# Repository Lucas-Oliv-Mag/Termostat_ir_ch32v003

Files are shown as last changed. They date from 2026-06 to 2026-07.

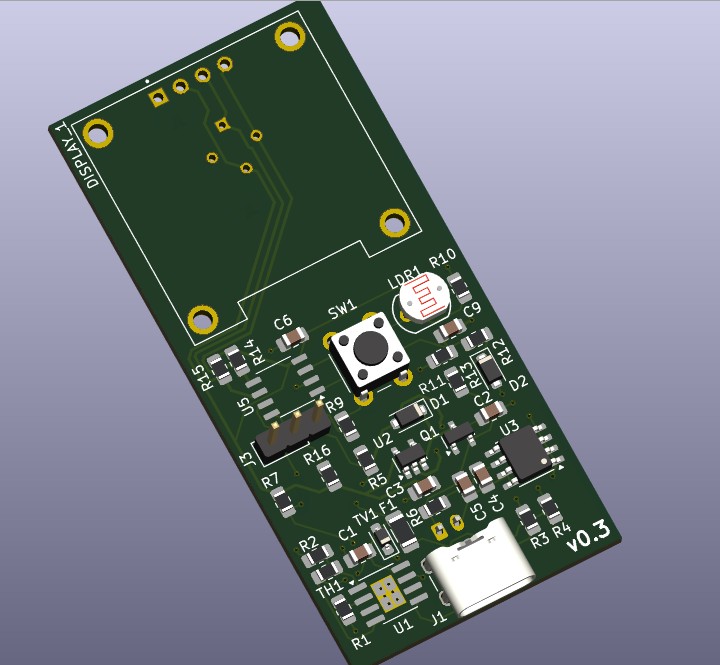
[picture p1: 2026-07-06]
docs/realises/v0.3/IR_Termostat_v0.3.jpg

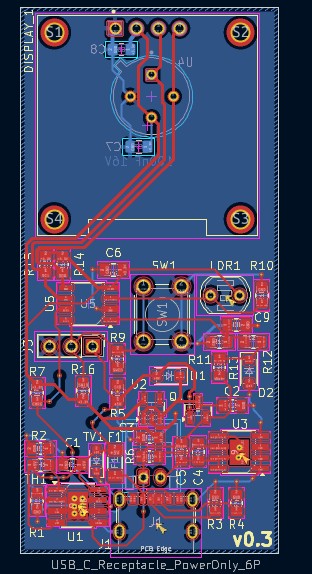
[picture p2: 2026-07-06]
docs/realises/v0.3/pcb_img.jpg

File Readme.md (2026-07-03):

# 🌡️ IR Thermostat — CH32V003

A portable, compact, low-power infrared thermometer based on the **CH32V003** microcontroller, featuring contactless temperature reading via the **MLX90614** sensor and an **I²C OLED SSD1306** display.

Built with **100% custom firmware** — HAL and sensor libraries written from scratch, with no dependency on third-party frameworks.

---

## ✨ Features

- 📡 Contactless infrared temperature reading via **MLX90614**
- 🖥️ **128x64 SSD1306 OLED** display over I²C
- 🔘 Single tactile button to trigger a reading
- 🌗 **Automatic brightness control** via a 5mm LDR (adjusts to ambient light)
- 🔋 **250mAh LiPo battery (503020)** for portable use
- ⚡ Charging via **TP4056** with integrated battery protection (0.5C)
- 🔌 3-pin header (5V / GND / SWIO) for external power and programming

---

## 🧩 Hardware

| Component | Description |
|---|---|
| **MCU** | CH32V003 (RISC-V, low cost, low power) |
| **Temperature sensor** | MLX90614 (IR, I²C) |
| **Display** | SSD1306 OLED 128x64, I²C |
| **Light sensor** | 5mm LDR (automatic brightness control) |
| **Input** | 1x tactile button (start/reading) |
| **Power source** | 250mAh LiPo battery, 503020 |
| **Charger** | TP4056 with battery protection (over-charge/discharge/current) |
| **Charge rate** | 0.5C (~125mA) |
| **External connector** | 3-pin header — 5V, GND, SWIO |

---

## ⚠️ Important warnings

> **Read carefully before using or programming the device.**

### 🚫 Never flash the MCU while pressing the button
The **SWIO** pin (used for programming/debugging) shares the same **I/O line** as the tactile button. Pressing the button during flashing can cause a **bus conflict**, flashing failure, or undefined MCU behavior.

### 🚫 Never connect USB while powering via the external 5V header
The **TP4056** charger and the 3-pin header **have no isolation between power sources**. Powering the circuit simultaneously through **USB** and the **external header (5V)** can cause:
- Short circuit between power sources
- Unwanted reverse current
- Damage to the TP4056, the battery, or the MCU

**Use only one power source at a time.**

---

## 🌡️ Operating conditions

- **Maximum recommended ambient temperature:** ~40 °C
- Above this limit, the MLX90614 sensor accuracy and the LiPo battery lifespan may be affected.

---

## 🔋 Battery and charging

| Parameter | Value |
|---|---|
| Capacity | 250 mAh |
| Model | 503020 (LiPo) |
| Charge rate | 0.5C (~125 mA) |
| Charge controller | TP4056 |
| Protection | Over-charge, over-discharge, and over-current |

---

## 💻 Firmware

The firmware is **built entirely from scratch**, without relying on any third-party HAL (such as the official WCH HAL), including:

- **Custom HAL** for GPIO, I²C, ADC, and timing on the CH32V003
- **Custom library** for MLX90614 communication
- **Custom library** for SSD1306 display control
- LDR reading routine with a brightness adjustment curve (PWM/lookup table)
- Simple state machine: `standby → reading → display → standby`

### repository structure

```
/firmware
  /*COMING SOON*
/hardware
  /schematics
  /pcb
  /datasheets
/docs
README.md
LICENSE
```

---

## 🚀 Usage

1. Power the device via battery (or the external 5V header, **never both at the same time**).
2. Press the tactile button to start a temperature reading.
3. The temperature will be shown on the OLED display.
4. The display brightness adjusts automatically based on the ambient light detected by the LDR.

---

## 🛠️ Flashing

1. Connect the programmer (WCH-Link or compatible) to the 3-pin header (**5V / GND / SWIO**).
2. **Make sure the tactile button is not being pressed.**
3. Flash normally using your preferred tool (e.g., `wchisp`, MounRiver, OpenOCD with RISC-V support).

---

## 🤝 Contributing

Suggestions, fixes, and improvements are welcome via issues or pull requests.

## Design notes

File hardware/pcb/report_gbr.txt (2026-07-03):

Plotted to 'H:\Meu Drive\WorkStation\Embarcados\Projetos\IR Termostat\hardware\pcb\IR_Termostat-F_Cu.gbr'.
Plotted to 'H:\Meu Drive\WorkStation\Embarcados\Projetos\IR Termostat\hardware\pcb\IR_Termostat-B_Cu.gbr'.
Plotted to 'H:\Meu Drive\WorkStation\Embarcados\Projetos\IR Termostat\hardware\pcb\IR_Termostat-F_Paste.gbr'.
Plotted to 'H:\Meu Drive\WorkStation\Embarcados\Projetos\IR Termostat\hardware\pcb\IR_Termostat-B_Paste.gbr'.
Plotted to 'H:\Meu Drive\WorkStation\Embarcados\Projetos\IR Termostat\hardware\pcb\IR_Termostat-F_Silkscreen.gbr'.
Plotted to 'H:\Meu Drive\WorkStation\Embarcados\Projetos\IR Termostat\hardware\pcb\IR_Termostat-B_Silkscreen.gbr'.
Plotted to 'H:\Meu Drive\WorkStation\Embarcados\Projetos\IR Termostat\hardware\pcb\IR_Termostat-F_Mask.gbr'.
Plotted to 'H:\Meu Drive\WorkStation\Embarcados\Projetos\IR Termostat\hardware\pcb\IR_Termostat-B_Mask.gbr'.
Plotted to 'H:\Meu Drive\WorkStation\Embarcados\Projetos\IR Termostat\hardware\pcb\IR_Termostat-Edge_Cuts.gbr'.
Created Gerber job file 'H:\Meu Drive\WorkStation\Embarcados\Projetos\IR Termostat\hardware\pcb\IR_Termostat-job.gbrjob'.
Informação: Done.
Informação: Done.

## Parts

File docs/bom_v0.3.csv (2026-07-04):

Reference | Qty | Value | DNP | Exclude from BOM | Exclude from Board | Footprint | Datasheet
BT1 | 1 | 250mAh |  | Excluído do BOM | Excluída da placa |  | ~
C1,C5 | 2 | 10uF 16V |  |  |  | Capacitor_SMD:C_0805_2012Metric_Pad1.18x1.45mm_HandSolder | ~
C2,C3 | 2 | 1uF 16V |  |  |  | Capacitor_SMD:C_0805_2012Metric_Pad1.18x1.45mm_HandSolder | ~
C4,C6,C7,C8,C9 | 5 | 100nF 16V |  |  |  | Capacitor_SMD:C_0805_2012Metric_Pad1.18x1.45mm_HandSolder | ~
D1 | 1 | PMEG2005EH |  |  |  | Diode_SMD:D_SOD-123F | https://assets.nexperia.com/documents/data-sheet/PMEGXX05EH_EJ_SER.pdf
D2 | 1 | BZT52C4V7 |  |  |  | Diode_SMD:D_SOD-123F | https://www.lcsc.com/datasheet/C2903911.pdf
DISPLAY_1 | 1 | DM-OLED096-636 |  |  |  | Library:MODULE_DM-OLED096-636
F1 | 1 | 250mA PPTC |  |  |  | Resistor_SMD:R_1206_3216Metric_Pad1.30x1.75mm_HandSolder | https://www.lcsc.com/datasheet/C70070.pdf
J1 | 1 | USB_C_Receptacle_PowerOnly_6P |  |  |  | Connector_USB:USB_C_Receptacle_GCT_USB4125-xx-x_6P_TopMnt_Horizontal | https://www.usb.org/sites/default/files/documents/usb_type-c.zip
J2 | 1 | JST-PH-2mm |  |  |  | Connector_JST:JST_PH_S2B-PH-K_1x02_P2.00mm_Horizontal | ~
J3 | 1 | Conn_01x03_Pin |  |  |  | Connector_PinHeader_2.54mm:PinHeader_1x03_P2.54mm_Vertical | ~
LDR1 | 1 | GL5516 |  |  |  | OptoDevice:R_LDR_5.1x4.3mm_P3.4mm_Vertical | http://www.tme.eu/de/Document/f2e3ad76a925811312d226c31da4cd7e/LDR07.pdf
Q1 | 1 | FDN306P |  |  |  | Package_TO_SOT_SMD:SOT-23 | https://www.lcsc.com/datasheet/C154510.pdf
R1,R7,R10 | 3 | 10K 1% |  |  |  | Resistor_SMD:R_0805_2012Metric_Pad1.20x1.40mm_HandSolder | ~
R2,R5,R16 | 3 | 22K 1% |  |  |  | Resistor_SMD:R_0805_2012Metric_Pad1.20x1.40mm_HandSolder | ~
R3,R4,R14,R15 | 4 | 5.1K 1% |  |  |  | Resistor_SMD:R_0805_2012Metric_Pad1.20x1.40mm_HandSolder | ~
R6,R9,R13 | 3 | 1K 1% |  |  |  | Resistor_SMD:R_0805_2012Metric_Pad1.20x1.40mm_HandSolder | ~
R11 | 1 | 2M 1% |  |  |  | Resistor_SMD:R_0805_2012Metric_Pad1.20x1.40mm_HandSolder | ~
R12 | 1 | 1M 1% |  |  |  | Resistor_SMD:R_0805_2012Metric_Pad1.20x1.40mm_HandSolder | ~
SW1 | 1 | SW_SPST |  |  |  | Button_Switch_THT:SW_PUSH_6mm | ~
TH1 | 1 | 10KF3950 NTC |  |  |  | Resistor_SMD:R_0805_2012Metric_Pad1.20x1.40mm_HandSolder | https://www.lcsc.com/datasheet/C2892549.pdf
TV1 | 1 | PESD5V0S1BA |  |  |  | Diode_SMD:D_SOD-323_HandSoldering | https://www.lcsc.com/datasheet/C2827694.pdf
U1 | 1 | TP4056-42-ESOP8 |  |  |  | Package_SO:SOIC-8-1EP_3.9x4.9mm_P1.27mm_EP2.41x3.3mm_ThermalVias | https://www.lcsc.com/datasheet/lcsc_datasheet_2410121619_TOPPOWER-Nanjing-Extension-Microelectronics-TP4056-42-ESOP8_C16581.pdf
U2 | 1 | TPS7A0233DBVR |  |  |  | Package_TO_SOT_SMD:SOT-23-5 | https://www.ti.com/lit/ds/symlink/tps7a02.pdf?ts=1783134422574
U3 | 1 | XB8089D |  |  |  | Package_SO:SOIC-8-1EP_3.9x4.9mm_P1.27mm_EP2.29x3mm_ThermalVias | https://www.lcsc.com/datasheet/C79928.pdf
U4 | 1 | MLX90614ESF-BAA-000-TU |  |  |  | Library:TO254P942H425-4 | https://www.lcsc.com/datasheet/C490604.pdf
U5 | 1 | CH32V003JxMx |  |  |  | Package_SO:SOP-8_3.9x4.9mm_P1.27mm | https://www.wch-ic.com/products/CH32V003.html

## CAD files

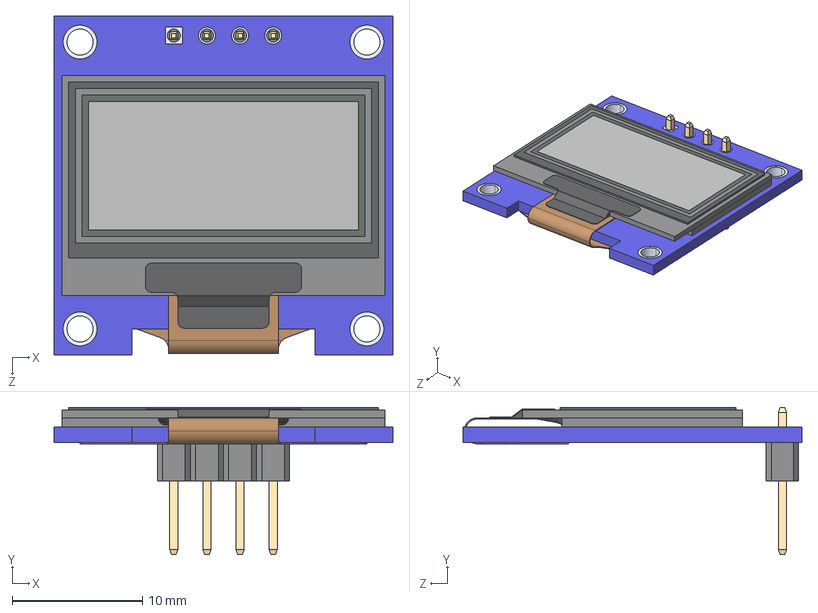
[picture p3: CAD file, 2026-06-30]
hardware/schematics/symbols_footprints/DM-OLED096-636/DM-OLED096-636.step
26.0 x 11.3 x 26.0 mm
DM-OLED096-636_Module
DM-OLED096-636_Panel

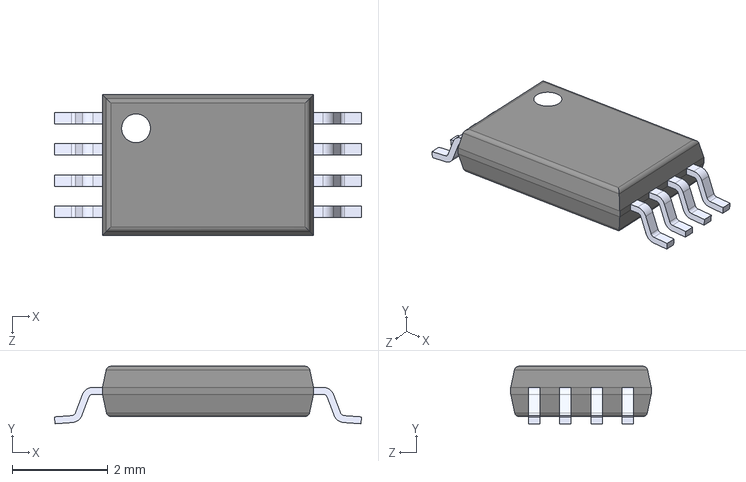
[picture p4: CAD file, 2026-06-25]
hardware/schematics/symbols_footprints/FS8205A/FS8205A.step
6.40 x 1.20 x 2.93 mm

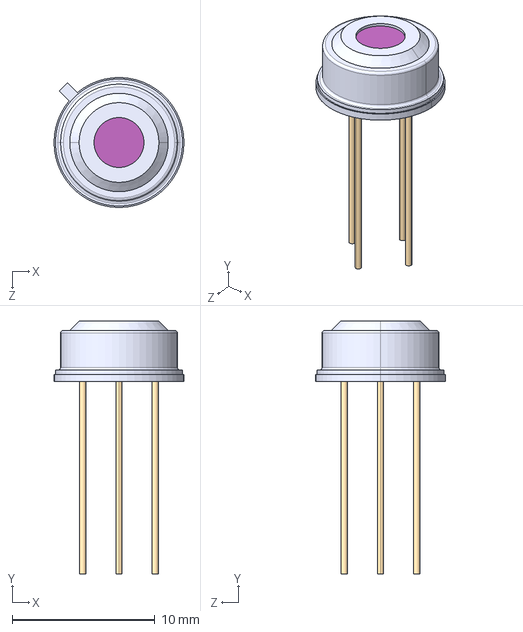
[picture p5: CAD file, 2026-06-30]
hardware/schematics/symbols_footprints/MLX90614ESF-BAA-000-TU/MLX90614ESF-BAA-000-TU.step
9.12 x 17.8 x 9.12 mm

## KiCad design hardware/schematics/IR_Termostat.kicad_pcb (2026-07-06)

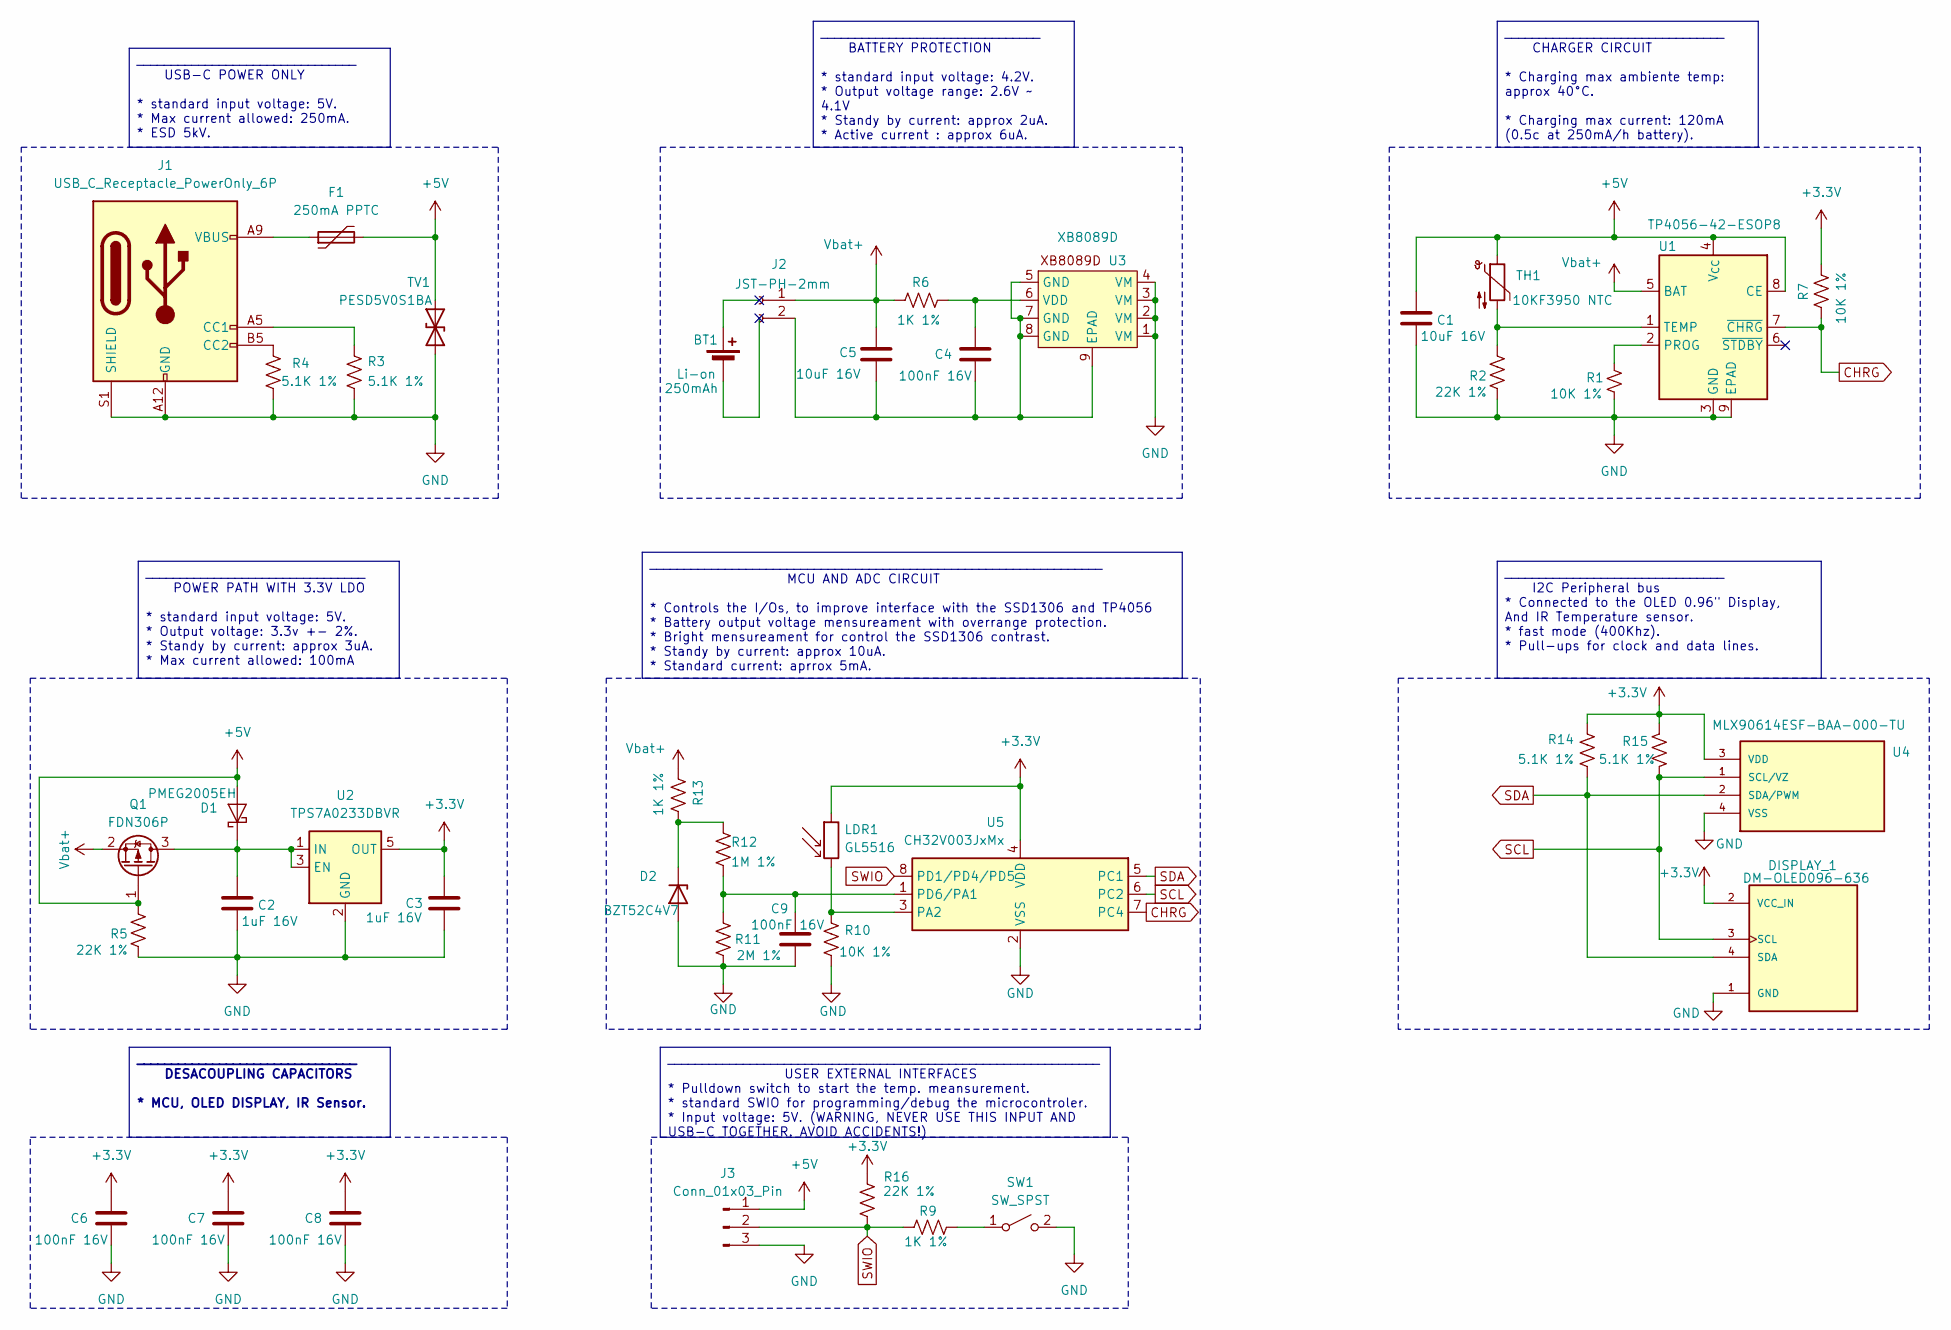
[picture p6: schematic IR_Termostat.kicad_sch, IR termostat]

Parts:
BT1: 250mAh
C1, C5: 10uF 16V; C_0805_2012Metric_Pad1.18x1.45mm_HandSolder
C2, C3: 1uF 16V; C_0805_2012Metric_Pad1.18x1.45mm_HandSolder
C4, C6, C7, C8, C9: 100nF 16V; C_0805_2012Metric_Pad1.18x1.45mm_HandSolder
D1: PMEG2005EH; D_SOD-123F
D2: BZT52C4V7; D_SOD-123F
DISPLAY_1: DM-OLED096-636; MODULE_DM-OLED096-636; PARTREV 2018-09-10
F1: 250mA PPTC; R_1206_3216Metric_Pad1.30x1.75mm_HandSolder
J1: USB_C_Receptacle_PowerOnly_6P; USB_C_Receptacle_GCT_USB4125-xx-x_6P_TopMnt_Horizontal
J2: JST-PH-2mm; JST_PH_S2B-PH-K_1x02_P2.00mm_Horizontal
J3: Conn_01x03_Pin; PinHeader_1x03_P2.54mm_Vertical
LDR1: GL5516; R_LDR_5.1x4.3mm_P3.4mm_Vertical
Q1: FDN306P; SOT-23
R1, R7, R10: 10K 1%; R_0805_2012Metric_Pad1.20x1.40mm_HandSolder
R2, R5, R16: 22K 1%; R_0805_2012Metric_Pad1.20x1.40mm_HandSolder
R3, R4, R14, R15: 5.1K 1%; R_0805_2012Metric_Pad1.20x1.40mm_HandSolder
R6, R9, R13: 1K 1%; R_0805_2012Metric_Pad1.20x1.40mm_HandSolder
R11: 2M 1%; R_0805_2012Metric_Pad1.20x1.40mm_HandSolder
R12: 1M 1%; R_0805_2012Metric_Pad1.20x1.40mm_HandSolder
SW1: SW_SPST; SW_PUSH_6mm
TH1: 10KF3950 NTC; R_0805_2012Metric_Pad1.20x1.40mm_HandSolder
TV1: PESD5V0S1BA; D_SOD-323_HandSoldering
U1: TP4056-42-ESOP8; SOIC-8-1EP_3.9x4.9mm_P1.27mm_EP2.41x3.3mm_ThermalVias
U2: TPS7A0233DBVR; SOT-23-5
U3: XB8089D; SOIC-8-1EP_3.9x4.9mm_P1.27mm_EP2.29x3mm_ThermalVias
U4: MLX90614ESF-BAA-000-TU; TO254P942H425-4; PARTREV 13
U5: CH32V003JxMx; SOP-8_3.9x4.9mm_P1.27mm

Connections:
+3.3V: C3.1, C6.1, C7.1, C8.1, DISPLAY_1.2 (VCC_IN), LDR1.1, R7.2, R14.2, R15.2, R16.2, U2.5 (OUT), U4.3 (VDD), U5.4 (VDD)
+5V: C1.1, D1.2 (A), F1.2, J3.1, Q1.1 (G), R5.1, TH1.1, TV1.2 (A2), U1.4 (V_{CC}), U1.8 (CE)
CHRG: R7.1, U1.7 (~CHRG), U5.7 (PC4)
GND: C1.2, C2.2, C3.2, C6.2, C7.2, C8.2, C9.2, D2.2 (A), DISPLAY_1.1 (GND), J1.A12 (GND), J1.B12 (GND), J1.S1 (SHIELD), J3.3, R1.2, R2.2, R3.2, R4.2, R5.2, R10.2, R11.2, SW1.2 (B), TV1.1 (A1), U1.3 (GND), U1.9 (EPAD), U2.2 (GND), U3.1 (VM), U3.2 (VM), U3.3 (VM), U3.4 (VM), U4.4 (VSS), U5.2 (VSS)
unnamed: C2.1, D1.1 (K), Q1.3 (D), U2.1 (IN), U2.3 (EN)
unnamed: D2.1 (K), R12.1, R13.1
unnamed: F1.1, J1.A9 (VBUS), J1.B9 (VBUS)
unnamed: J1.A5 (CC1), R3.1
unnamed: J1.B5 (CC2), R4.1
unnamed: C4.2, C5.2, J2.2, U3.5 (GND), U3.7 (GND), U3.8 (GND), U3.9 (EPAD)
unnamed: R9.2, SW1.1 (A)
unnamed: R1.1, U1.2 (PROG)
unnamed: R2.1, TH1.2, U1.1 (TEMP)
unnamed: C4.1, R6.2, U3.6 (VDD)
unnamed: LDR1.2, R10.1, U5.3 (PA2)
unnamed: C9.1, R11.1, R12.2, U5.1 (PD6/PA1)
SCL: DISPLAY_1.3 (SCL), R15.1, U4.1 (SCL/VZ), U5.6 (PC2)
SDA: DISPLAY_1.4 (SDA), R14.1, U4.2 (SDA/PWM), U5.5 (PC1)
SWIO: J3.2, R9.1, R16.1, U5.8 (PD1/PD4/PD5)
Vbat+: C5.1, J2.1, Q1.2 (S), R6.1, R13.2, U1.5 (BAT)

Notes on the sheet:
__________________________________________________________________ MCU AND ADC CIRCUIT * Controls the I/Os, to improve interface with the SSD1306 and TP4056 * Battery output voltage mensureament with overrange protection. * Bright mensureament for control the SSD1306 contrast. * Standy by current: 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
________________________________ I2C Peripheral bus * Connected to the OLED 0.96" Display, And IR Temperature sensor. * fast mode (400Khz). * Pull-ups for clock and data lines.
________________________________ DESACOUPLING CAPACITORS * MCU, OLED DISPLAY, IR Sensor.
________________________________ POWER PATH WITH 3.3V LDO * standard input voltage: 5V. * Output voltage: 3.3v +- 2%. * Standy by current: approx 3uA. * Max current allowed: 100mA
_______________________________________________________________ USER EXTERNAL INTERFACES * Pulldown switch to start the temp. meansurement. * standard SWIO for programming/debug the microcontroler. * Input voltage: 5V. (WARNING, NEVER USE THIS INPUT AND USB-C TOGETHER. AVOID ACCIDENTS!)
________________________________ CHARGER CIRCUIT * Charging max ambiente temp: approx 40°C. * Charging max current: 120mA (0.5c at 250mA/h battery).
________________________________ USB-C POWER ONLY * standard input voltage: 5V. * Max current allowed: 250mA. * ESD 5kV.
________________________________ BATTERY PROTECTION * standard input voltage: 4.2V. * Output voltage range: 2.6V ~ 4.1V * Standy by current: approx 2uA. * Active current : approx 6uA.

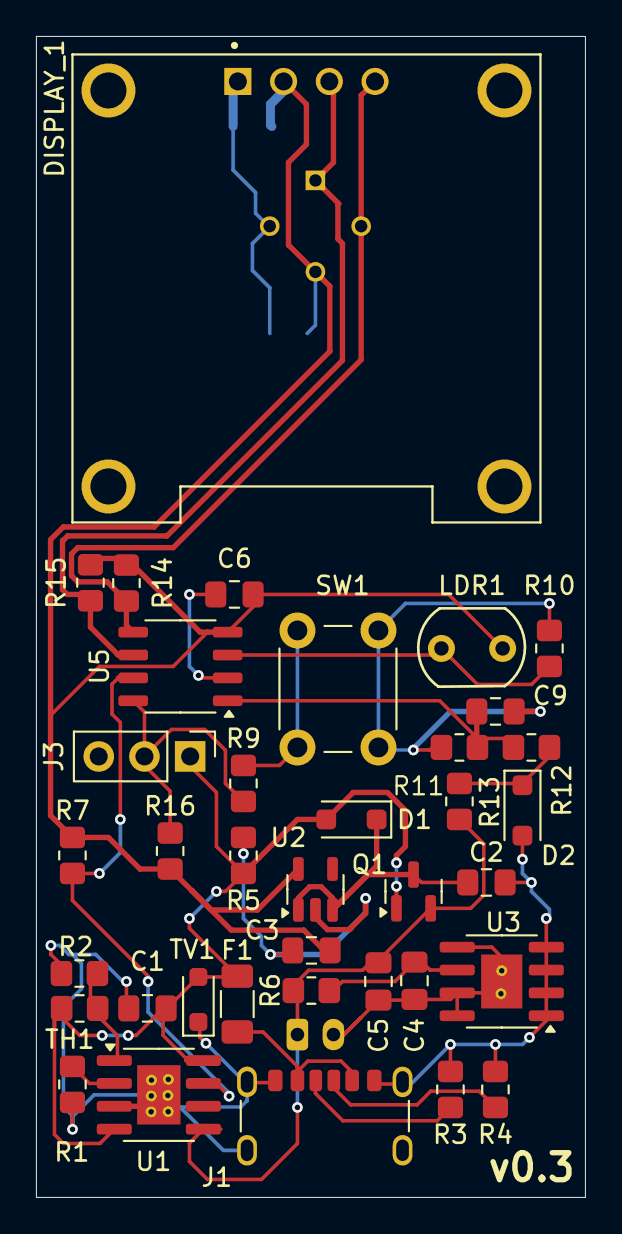
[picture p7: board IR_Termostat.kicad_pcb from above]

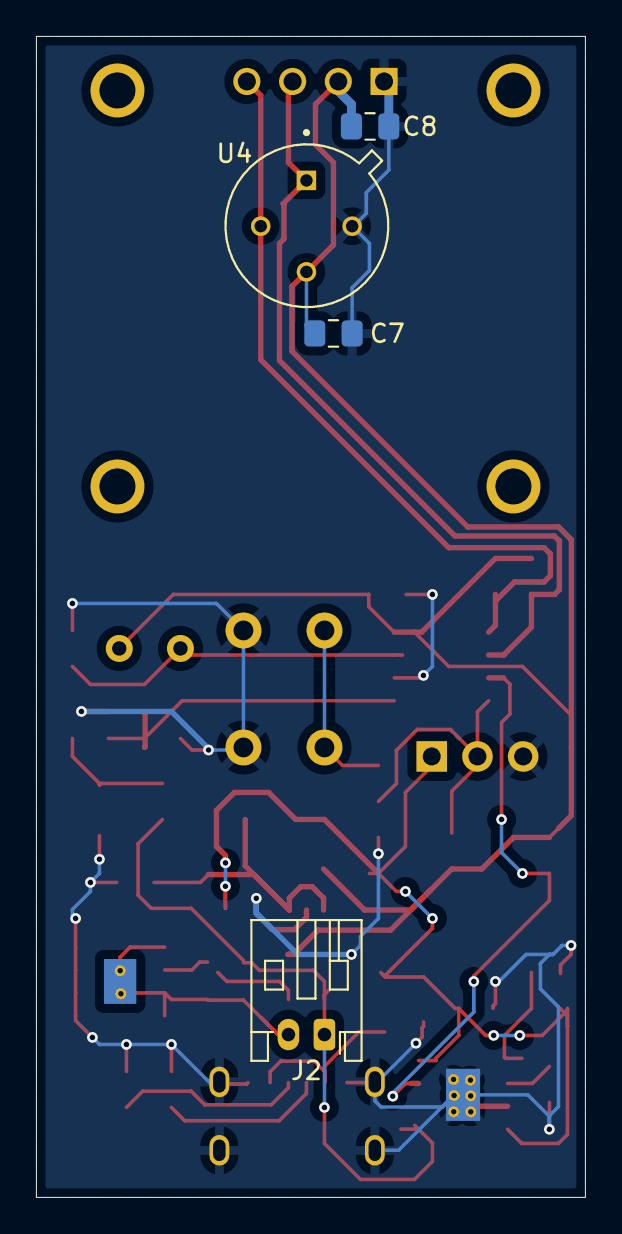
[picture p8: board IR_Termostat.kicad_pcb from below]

Board: 2 copper layers, 30.5 x 64.5 mm, 41 parts (4 on the bottom side), 20 nets.

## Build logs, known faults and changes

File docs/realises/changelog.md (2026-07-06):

## CHANGELOG ##

# Initial versions
* v0.3 JCL PCB compliance.   - (05/07/26).
* v0.2 LDO and ADC upgrades. - (03/07/26).
* v0.1 First PCB.            - (01/07/26).

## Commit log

2026-06-25 Initial commit
    Hardware project start
    [IR_Termostat.kicad_pcb, IR_Termostat.kicad_sch]
2026-06-25 Feat: NTC improved
    Also added CC1 and CC2 Resistors and a text box explaining the eletrical tolerances
    [IR_Termostat.kicad_sch]
2026-06-25 Style: Schematic refactored by sectors
    [FS8205A.step, IR_Termostat.kicad_sch]
2026-06-26 Feat: Power path with LDO implemented
    Using high efficiency componentes to minimize the voltage drop-out and heat sink, for allowed levels
    [IR_Termostat.kicad_sch]
2026-06-26 feat: Battery protection circuit implemented
    Added a protection resiable IC for: Over and Under charge, short, inverse polarity
    [IR_Termostat.kicad_pcb, IR_Termostat.kicad_sch]
2026-06-26 feat: pullup resistor to charge IC I/Os
    Also redesingned the sch. for better visual
    [IR_Termostat.kicad_sch]
2026-06-27 Fix: Switched Pullup resistors source from TP4056
    Before, the resistors responsable for the pullup of the CHRGD and STDBY pins from the charger IC are connect on 5V line, now they are on 3.3V power supply from LDO.
    [IR_Termostat.kicad_sch]
2026-06-27 Feat: main MCU and ADC
    Included the CH32V003J4M6, also bring up a voltage divider with overrange protection to read the battery voltage with realible, and brightness mensurement with another ADC channel.
    [IR_Termostat.kicad_sch]
2026-06-28 feat: External interface improviment.
    Included a header pin por programming/debuging the embedded, also added decoupling capacitors and a touch switch for make interface with the MCU
2026-06-28 Feat: Added I2C Bus peripherals
    [IR_Termostat.kicad_sch]
2026-06-30 Fix: I2C Peripheral bus footprint and symbol
    [DM-OLED096-636.step, MLX90614ESF-BAA-000-TU.step]
2026-06-30 Fix: power path mosfet footprint
    The footprint of the power path mosfet now it's pin-to-pin with the skemathic.
    [IR_Termostat.kicad_pcb, IR_Termostat.kicad_sch]
2026-07-02 Feat: First components layout
    [IR_Termostat.kicad_pcb]
2026-07-02 feat: initial commit on pcb branch
    Actual status: Only components layout finished without their connections
    [IR_Termostat.kicad_sch]
2026-07-03 feat: first pcb v0.1
    [IR_Termostat.kicad_pcb]
2026-07-03 feat: ReadMe added, folders archtecture, changelog & bom markdown files improve
    This commit start this repository to the world wide standard patterns
    [DM-OLED096-636.step, FS8205A.step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]
2026-07-03 style: bom.md organization
    added numbers in rows, also bold the first column
2026-07-04 Fix: LDO and Schotcky diode Vf optimized
    Switched this components for minimum voltage dropout, by tps7a02 LDO and PMEG2005 diode
2026-07-04 Fix: Battery mensurement circuit upgrade
    Better Iq by 100x and a capacitor to filter noises, also refresh the pcb
    [IR_Termostat-B_Cu.gbr, IR_Termostat-B_Mask.gbr, IR_Termostat-B_Paste.gbr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]
2026-07-04 fix: schematic datasheets fixed, and docs upgrade by realises
    Now the BOM it's up-to-date with the schematic datasheets by versions
    [IR_Termostat-B_Cu.gbr, IR_Termostat-B_Mask.gbr, IR_Termostat-B_Paste.gbr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]
2026-07-06 Fix: LCSC Compliance
    This commit fix the pcb, branching a new version v0.3, thats it's side-by-side with the LCSC DFM check
    [IR_Termostat-B_Cu.gbr, IR_Termostat-B_Mask.gbr, IR_Termostat-B_Paste.gbr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]
